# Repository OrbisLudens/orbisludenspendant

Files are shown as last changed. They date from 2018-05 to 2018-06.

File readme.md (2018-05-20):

## Orbis Ludens Pendant

The technical part of the Orbis Ludens pendant, based on a ESP8266 Arduino, Neopixel Ring and the Tecthulu API

## Requirements:

### Hardware
* ESP8266 (WeMos D1 Mini or compatible model)
* Neopixel Ring 8 Leds (or compatible model)

### Software
* Arduino IDE (best to use, especially to download the board information and the libraries)
* CH340G Driver for USB to Serial Connection (https://wiki.wemos.cc/downloads). You need to install it (at least on MacOS to see the serial port of the Wemos D1 Mini)

### Arduino IDE
#### Libraries
To compile the sketch the following libraries need to be installed:

* ArduinoJson
* WifiManager (tzapu)
* Adafruit Neopixel
* DNSServer
* DoubleResetDetect (NOT DoubleResetDetect_or_)
* ESP8266HTTPClient
* ESP8266WebServer

#### Addition Board Information
We need to add the ESP8266 board definitions:

In the IDE add an additional Board Manager URL:

* Settings -> Additional Board Manager URL: http://arduino.esp8266.com/stable/package\_esp8266com\_index.json

Now choose the Board in the Board Manager:
* Tools -> Board -> Board Manager -> Search for "esp8266" -> Install
* Select the "Wemos D1 R2 & mini" board
* Select the port

## Configuration

* Copy url.h.example to url.h and configure the URL
* Copy wifi.h.example to wifi.h and configure the SSID and the password for the AP which will be spawned if a double reset is detected

### The configuration AP
The device can be configured by pressing the reset button 2 times within 3 seconds. After that an access point (ssid, password configured in wifi.h) spawns with a capative portal and redirects all traffic to the configuration URL. The main configuration can be found under "Wifi Configuration".

In the Wifi Configuration tab you can configure the AP the pendant should connect to. Furthermore the URL of the Tecthulu Device can be specified.

If you want to operate in offline mode you can set "offline_mode" to y or n (yes or no) and the color (r for resistance, e for enlightend, everything else will set the color to white). In the offline mode all leds will pulse. If you want to disable the offline mode you need to reenter the configuration gui and set offline_mode to n.

All data will be saved in the eeprom of the arduino. To delete this data you need to recompile the code and uncomment the line "SPIFFS.format()"

### Reconfigure
To manually spawn the AP double press the reset button. The device will boot up again and spawn the AP.

## What does it do
The Orbis Ludent Pendant is an pendant like object which interacts with the Orbis Ludent Portal on the Osiris Ephiphany Night Event on Schloss Kaltenberg (Ingress related event).
Whenever the portal resonators change the pendant show that change with 8 ultrabright leds. This works only near the Portal (technical: within the range of the configured Wifi AP).

The device can be set to an offline mode where it pulses in the chosen faction color.

### Example
Prototype with a 12 LED Ring (4 for mods, not used): https://www.youtube.com/watch?v=4cp5gsIQYR0

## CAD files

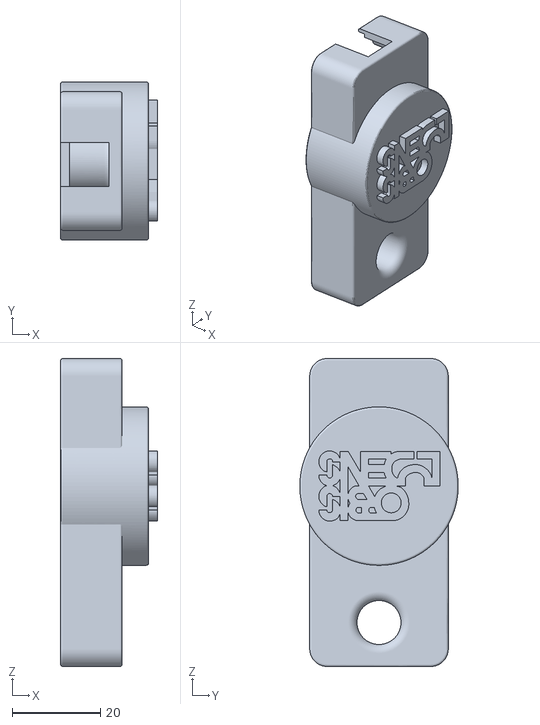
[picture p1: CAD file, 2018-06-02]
stl/SCHFRE_Teil1.stl
22.0 x 36.0 x 70.0

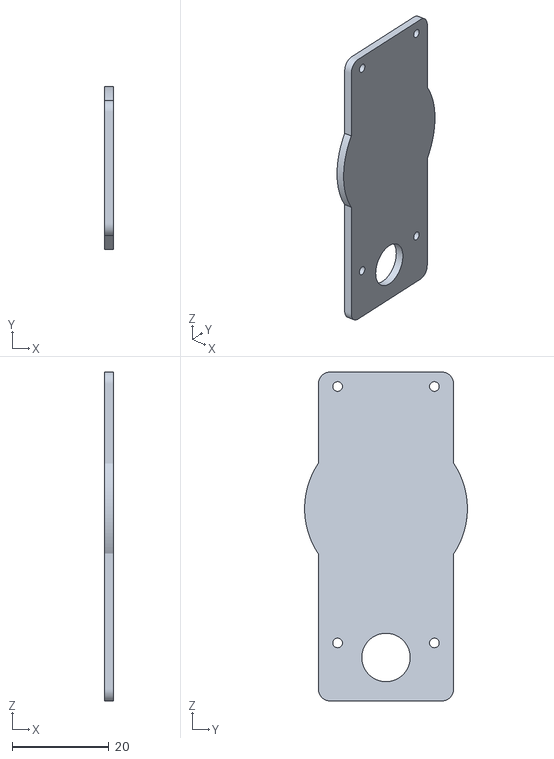
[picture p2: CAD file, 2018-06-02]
stl/SCHFRE_Teil2.stl
1.90 x 33.6 x 68.0

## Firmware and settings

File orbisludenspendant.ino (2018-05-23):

#include "orbisludenspendant.h"
#include "wifi.h"
#include "url.h"

// When we setup the NeoPixel library, we tell it how many pixels, and which pin to use to send signals.
Adafruit_NeoPixel pixels = Adafruit_NeoPixel(NUMPIXELS, PIN, NEO_GRB + NEO_KHZ800);

void setup () {

  pinMode(LED_BUILTIN, OUTPUT);     // Initialize the LED_BUILTIN pin as an output
  digitalWrite(LED_BUILTIN, LOW);   // Turn the LED on (Note that LOW is the voltage level

  pixels.begin(); // This initializes the NeoPixel library.
  pixels.show(); // Initialize all pixels to 'off'



  Serial.begin(BAUD_RATE); // Set serial Speed
  Serial.println(); // newline to get rid of the serial garbage


  //clean FS, for testing
  // SPIFFS.format();


  // From https://github.com/tzapu/WiFiManager/tree/master/examples/AutoConnectWithFSParameters
  // read configuration from FS json
  Serial.println("mounting FS...");
  loadConfig();


  // Initialize and configure Wifimanager
  WiFiManager wifiManager;
  WiFiManagerParameter tecthulu_url("tecurl", "tecthulu url", tecurl, 100);
  WiFiManagerParameter wifi_offline_mode("offline_mode", "offline mode enabled (yes/no)", offline_mode, 3);
  WiFiManagerParameter wifi_offline_faction("offline_faction", "offline faction (e/r)", offline_faction, 3);
  wifiManager.setSaveConfigCallback(saveConfigCallback);
  wifiManager.setAPCallback(configModeCallback);
  wifiManager.addParameter(&tecthulu_url);
  wifiManager.addParameter(&wifi_offline_mode);
    wifiManager.addParameter(&wifi_offline_faction);

  // Double Reset == Enter Config AP
  if (drd.detect()) {
    Serial.println("Double Reset Detected");
    wifiManager.setBreakAfterConfig(true);
    wifiManager.startConfigPortal(wm_ssid, wm_password);
    Serial.println("After Configportal: Save Config");
    saveConfig();
  } else {
    Serial.println("No Double Reset Detected");
  }

  //read updated parameters
  strcpy(tecurl, tecthulu_url.getValue());
  strcpy(offline_mode, wifi_offline_mode.getValue());
  strcpy(offline_faction, wifi_offline_faction.getValue());

  if (String(offline_mode) == "y") {
    WiFi.mode(WIFI_OFF);
    Serial.println("offline mode enabled");
  } else {
    // try to connect or spawn AP if no saved values
    // We disable autoconnect so the Config portal is only activated by double reset
    // wifiManager.autoConnect(wm_ssid, wm_password);
    Serial.println("connected");
  }
   //save the custom parameters to FS
  if (shouldSaveConfig) {
    saveConfig();
  }
  digitalWrite(LED_BUILTIN, HIGH);  // Turn the LED off by making the voltage HIGH
}

void loop() {
  String pos;
  String portalres[8];
  int reshealth[8];
  int health;

  Serial.println("---");
  if (String(offline_mode) == "y" ||  WiFi.status() != WL_CONNECTED) {
    // call the offline mode
    offlineMode();
    delay(100);    // loop through the offline cycle
  } else if (WiFi.status() == WL_CONNECTED) { //Check WiFi connection status

    pixels.setBrightness(255); // set to max brightness. We need to do that because the offline mode changes only the global brightness
    HTTPClient http;  //Declare an object of class HTTPClient

    http.begin(tecurl);  //Specify request destination
    int httpCode = http.GET();  //Send the request

    if (httpCode > 0) { //Check the returning code

      String payload = http.getString();   //Get the request response payload
      //Serial.println(payload);             //Print the response payload
      StaticJsonBuffer<2000> JSONBuffer; // 2000 byte is the max length of a message
      JsonObject& tec_answer = JSONBuffer.parseObject(payload);

      int faction = factionMapping(tec_answer["result"]["controllingFaction"]); // Controlling faction. 0=none, 1=ENL, 2=RES
      Serial.println(faction);
      Serial.println(tec_answer["result"]["resonators"].as<String>());
      int deployedresos = tec_answer["result"]["resonators"].size(); // Number of deployed resonators
      Serial.printf("Deployed Resos: %d\n", deployedresos);
      // Iterate over the json resonator subarray and get the health and the position
      for (int i = 0; i < deployedresos; i++) {
        reshealth[i] = (int) tec_answer["result"]["resonators"][i]["health"];
        portalres[i] = tec_answer["result"]["resonators"][i]["position"].as<String>();
      }
      // Now iterate over the pixels and see if we have a resonator to show
      for (int i = 0; i < NUMPIXELS; i++) {
        Serial.printf("-------        Checking >> %s <<\n", resonatorleds[i]);
        int pos = isvalueinarray((String)resonatorleds[i], portalres, 8);
        if (pos != -1 ) {
          // light led with faction color
          health = reshealth[pos];
          Serial.printf("%d: faction color (%d health)\n", i, health);
          int color[3] = {0, 0, 0};
          color[faction]=health;
          setPixel(i, color[0], color[1], color[2]);

        } else {
          // light led with white or clear led if the resonator is not captured
          Serial.printf("%d: grey color!\n", i);
          setPixel(i, 2, 2, 2);
        }
      }
    }
    http.end();   //Close connection
    delay(5000);    //Send a request every 5 seconds
  }
}

//callback notifying us of the need to save config
void saveConfigCallback () {
  Serial.println("Should save config");
  shouldSaveConfig = true;
}

// callback to enter config mode if reset button is pressed twice
void configModeCallback (WiFiManager *myWiFiManager) {
  Serial.println("Entered config mode");
  Serial.println(WiFi.softAPIP());
}

// Loads the config from the eeprom
void loadConfig() {
  if (SPIFFS.begin()) {
    Serial.println("mounted file system");
    if (SPIFFS.exists("/config.json")) {
      //file exists, reading and loading
      Serial.println("reading config file");
      File configFile = SPIFFS.open("/config.json", "r");
      if (configFile) {
        Serial.println("opened config file");
        size_t size = configFile.size();
        // Allocate a buffer to store contents of the file.
        std::unique_ptr<char[]> buf(new char[size]);

        configFile.readBytes(buf.get(), size);
        DynamicJsonBuffer jsonBuffer;
        JsonObject& json = jsonBuffer.parseObject(buf.get());
        json.printTo(Serial);
        if (json.success()) {
          Serial.println("\nparsed json");
          strcpy(tecurl, json["tecurl"]);
          strcpy(offline_mode, json["offline_mode"]);
          strcpy(offline_faction, json["offline_faction"]);
        } else {
          Serial.println("failed to load json config");
        }
      }
    }
  } else {
    Serial.println("failed to mount FS");
  }
  //end read
}

// Writes the config to the eeprom
void saveConfig() {
 Serial.println("saving config");
  DynamicJsonBuffer jsonBuffer;
  JsonObject& json = jsonBuffer.createObject();
  json["tecurl"] = tecurl;
  json["offline_mode"] = offline_mode;
  json["offline_faction"] = offline_faction;

  File configFile = SPIFFS.open("/config.json", "w");
  if (!configFile) {
    Serial.println("failed to open config file for writing");
  }

  json.printTo(Serial);
  json.printTo(configFile);
  configFile.close();
  //end save

}


// faction mapping, to get an integer value for the faction. The int will be used to address the
// setPixelColor from the Neopixel lib
// None: 0, Enl: 1, Res: 2
int factionMapping(String faction) {
  if (faction == "Enlightened" || faction == "enlightened") {
    return 1;
  }
  if (faction == "Resistance" || faction == "resistance") {
    return 2;
  }
  return 0;
}

// Find the LED according to the position
int findLedPosition(String pos) {
  for (int i = 0; i < sizeof(resonatorleds)-1; i++) {
    if ((String) resonatorleds[i] == pos) {
      return i;
    }
  }
  return -1;
}

// Search a value in an array and return the position
int isvalueinarray(String val, String arr[], int size){
    int i;
    for (i = 0; i < size; i++) {
        if (val.equals(arr[i])) {
            return i;
        }
    }
    return -1;
}

// Light up that pixel!
void setPixel(int pos, int r, int g, int b) {
  Serial.printf("Set Pixel %d to (%d, %d, %d)\n", pos, r, g, b);
  pixels.setPixelColor(pos, r, g, b);
  pixels.show();
}

// function for offline mode
void offlineMode() {
  if (String(offline_faction) == "e") {
    pulsecolor = pixels.Color(0, 255, 0);
  } else if (String(offline_faction) == "r") {
    pulsecolor = pixels.Color(0, 0, 255);
  } else {
    pulsecolor = pixels.Color(255, 255, 255);
  }
  cur_bright = 20;
  FactionPulse(80, false);
}

// FactionPulse for offline mode
// We change the overall brightness. This is not recommended but for this is the only
// task and we do not run into timing issues we can use it here.
// Normally we change the brightness within each Led with setPixelColor()
void FactionPulse(uint8_t wait, boolean fade) {
  uint16_t i,j;
  for(j=0; j<40; j++) {
    PulseBrightness(5, fade, 40);
    for(i=0; i<pixels.numPixels(); i++) {
      pixels.setPixelColor(i, pulsecolor);
    }
    pixels.show();
    delay(wait);
    if (fade && cur_bright == 0) {
      break;
    }
  }
}

// Pulse brightness
void PulseBrightness(uint8_t step, boolean fade, uint8_t maxb) {
  if (fade && (cur_bright+bright_diff) <= step ) {
    cur_bright=0;
  }
  else {
    if (cur_bright >= maxb) {
      bright_diff=-step;
    }
    else if (cur_bright <= 5) {
      bright_diff=step;
    }
    cur_bright=cur_bright+bright_diff;
  }
  pixels.setBrightness(cur_bright); //adjust brightness here
}

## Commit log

2018-04-13 Set PIN to 14. Reduce brightness of no reso deployed
2018-04-14 Switched to Wifimanager
2018-04-15 Added tecthulu url as custom value in the Wifimanager Config Portal Added double reset detection: If a DR is detected the config portal will be started.
    [orbisludenspendant.ino]
2018-05-20 Moved from DoubleResetDetector to DoubleResetDectet Fixed Errors with SPIFFS First changes for new API
    [orbisludenspendant.ino]
2018-05-20 Switched to new tecthulu API
2018-06-02 Added STL files for casing
    [SCHFRE_Teil1.stl, SCHFRE_Teil2.stl]
